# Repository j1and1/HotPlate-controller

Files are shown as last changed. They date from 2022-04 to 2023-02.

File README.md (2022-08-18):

# Hotplate reflow controller

This is still a work in progress, and controller code has issues of overshooting the target temperature **use at your own risk.** 

This is a implementation of temperature control of heated plate for reflow soldering.

## Wiring

To make this you will need:
1. Arduino pro mini (or any other microcontroller)
2. Thermal resistor (I used 100k one from my 3d printer spares)
3. 4.7kOhm resistor for temperature resistor pullup
4. 10uF capacitor for stabilizing sensor value
5. Nokia 5510 display module (Or other display module... code might need to be patched for this though)
6. Solid state relay (use solid state relay to avoid arking when Arduino enables disables the output pin)
7. if Arduino runs on 5V you will need additional 5 10k resistors and one 1kOhm resistors on the SPI line ment for display.

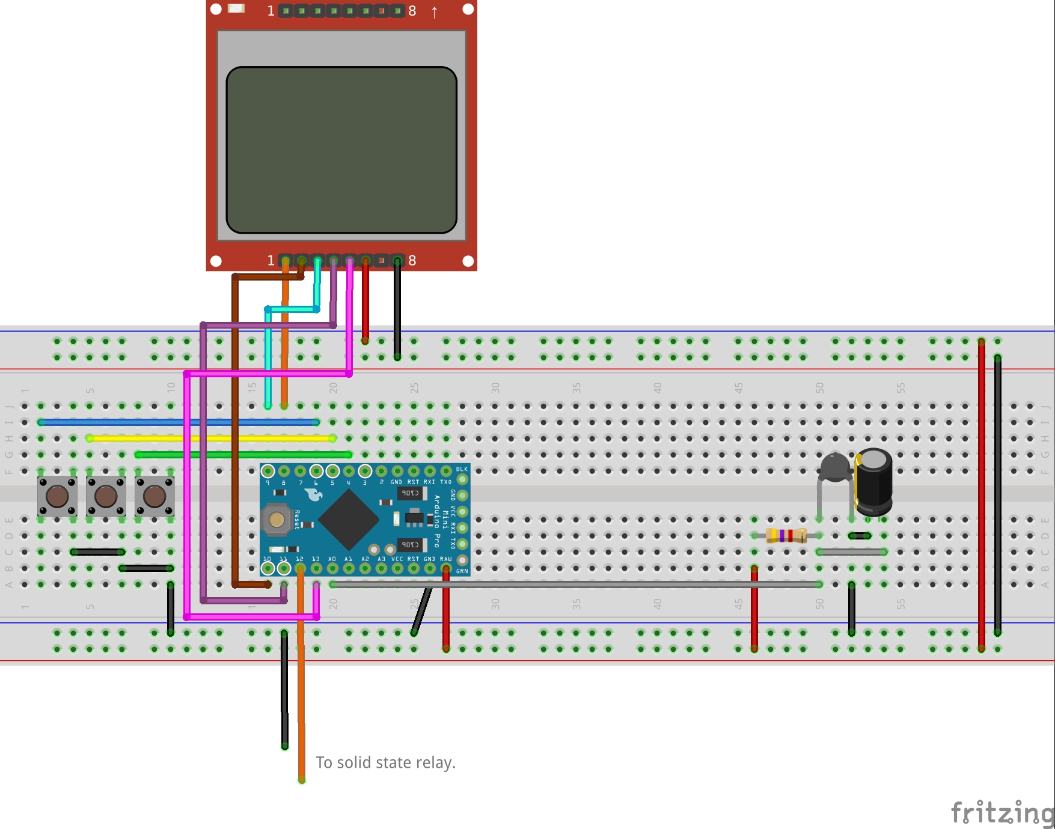
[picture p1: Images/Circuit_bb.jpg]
Schematic


## Compiling code

To compile Arduino code you will need few additional libraries.
1. Thermistor library [from here](https://github.com/miguel5612/ThermistorLibrary) or Arduino IDE library section
2. Adafruit PCD8544 library from Arduino IDE library section [or here](https://github.com/adafruit/Adafruit-PCD8544-Nokia-5110-LCD-library). Dont forget to install dependencies for it too.

## Known issues
- Thermal runaway algorithm is ignoring the state of solid state relay output pin
- Controller code does not account for thermal mass of the heater and plate. This will get solved once PID algorithm is added.

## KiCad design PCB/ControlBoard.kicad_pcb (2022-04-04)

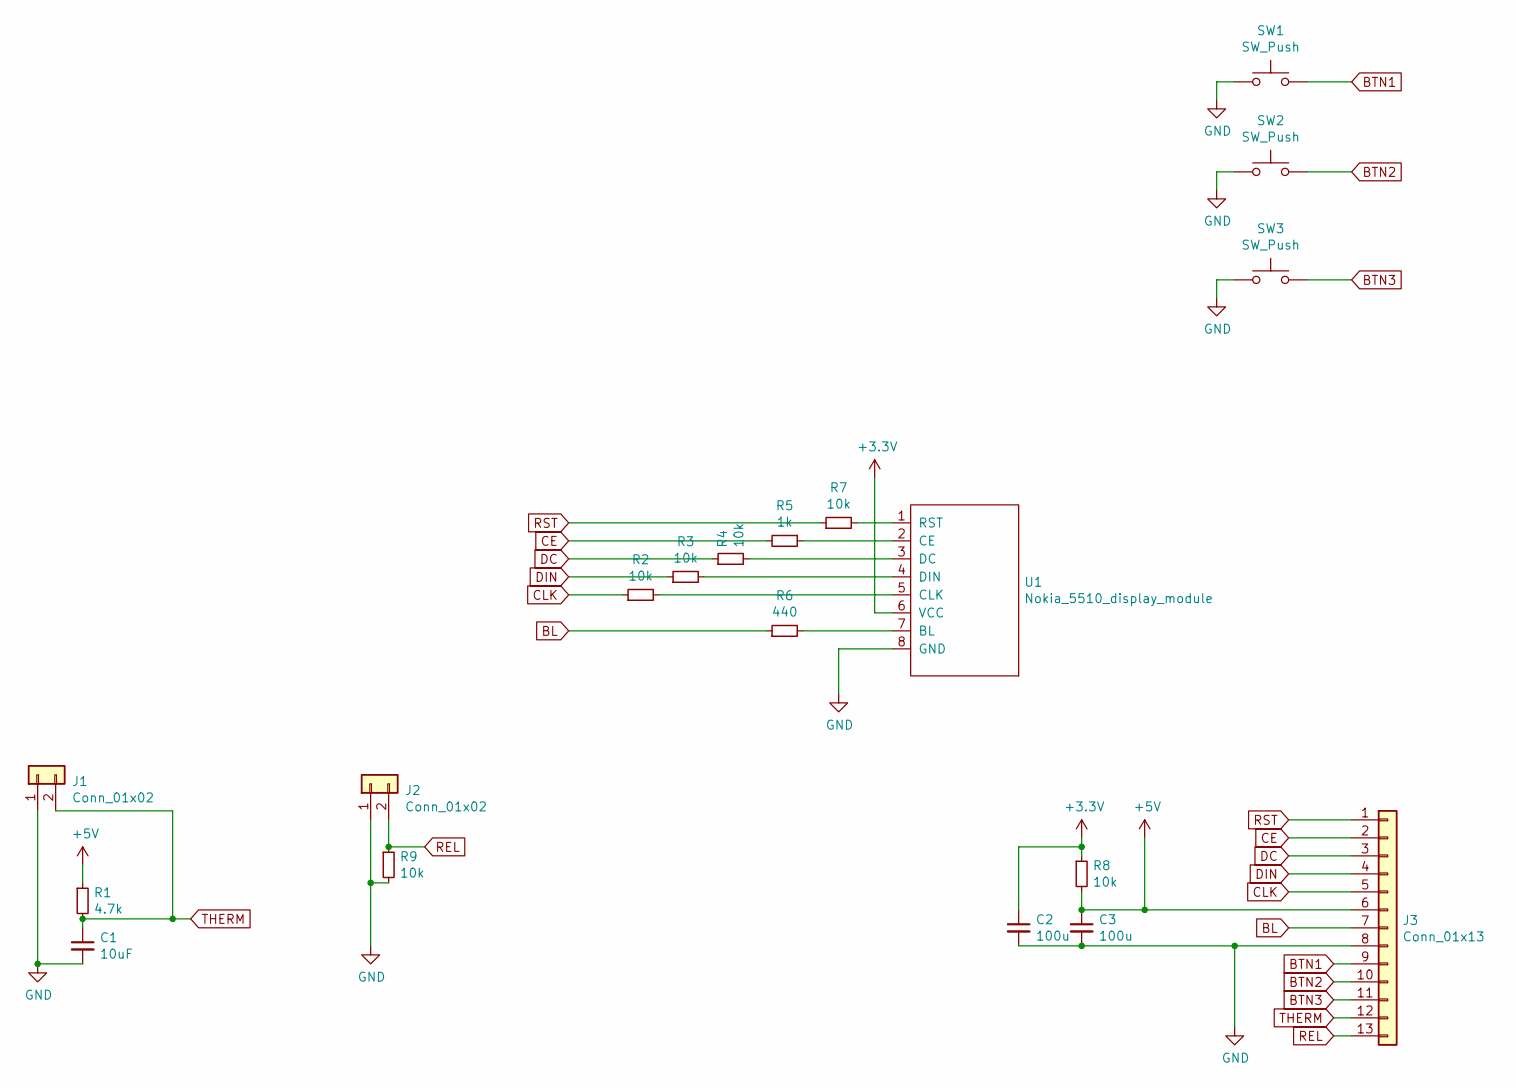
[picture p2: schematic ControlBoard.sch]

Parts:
C1: 10uF; C_0603_1608Metric_Pad1.08x0.95mm_HandSolder
C2, C3: 100u; C_0603_1608Metric_Pad1.08x0.95mm_HandSolder
J1, J2: Conn_01x02; PinHeader_1x02_P2.54mm_Horizontal
J3: Conn_01x13; PinHeader_1x13_P2.54mm_Vertical
R1: 4.7k; R_0402_1005Metric_Pad0.72x0.64mm_HandSolder
R2, R3, R4, R7, R8, R9: 10k; R_0402_1005Metric_Pad0.72x0.64mm_HandSolder
R5: 1k; R_0402_1005Metric_Pad0.72x0.64mm_HandSolder
R6: 440; R_0402_1005Metric_Pad0.72x0.64mm_HandSolder
SW1, SW2, SW3: SW_Push; SW_PUSH_6mm
U1: Nokia_5510_display_module; NOKIA_5510_display_module

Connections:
+3V3: C2.1, R8.1, U1.6 (VCC)
+5V: C3.1, J3.6, R1.1, R8.2
BL: J3.7, R6.1
BTN1: J3.9, SW1.2
BTN2: J3.10, SW2.2
BTN3: J3.11, SW3.2
CE: J3.2, R5.2
CLK: J3.5, R2.1
DC: J3.3, R4.1
DIN: J3.4, R3.1
GND: C1.2, C2.2, C3.2, J1.1, J2.1, J3.8, R9.2, SW1.1, SW2.1, SW3.1, U1.8 (GND)
unnamed: R2.2, U1.5 (CLK)
unnamed: R3.2, U1.4 (DIN)
unnamed: R4.2, U1.3 (DC)
unnamed: R5.1, U1.2 (CE)
unnamed: R6.2, U1.7 (BL)
unnamed: R7.2, U1.1 (RST)
REL: J2.2, J3.13, R9.1
RST: J3.1, R7.1
THERM: C1.1, J1.2, J3.12, R1.2

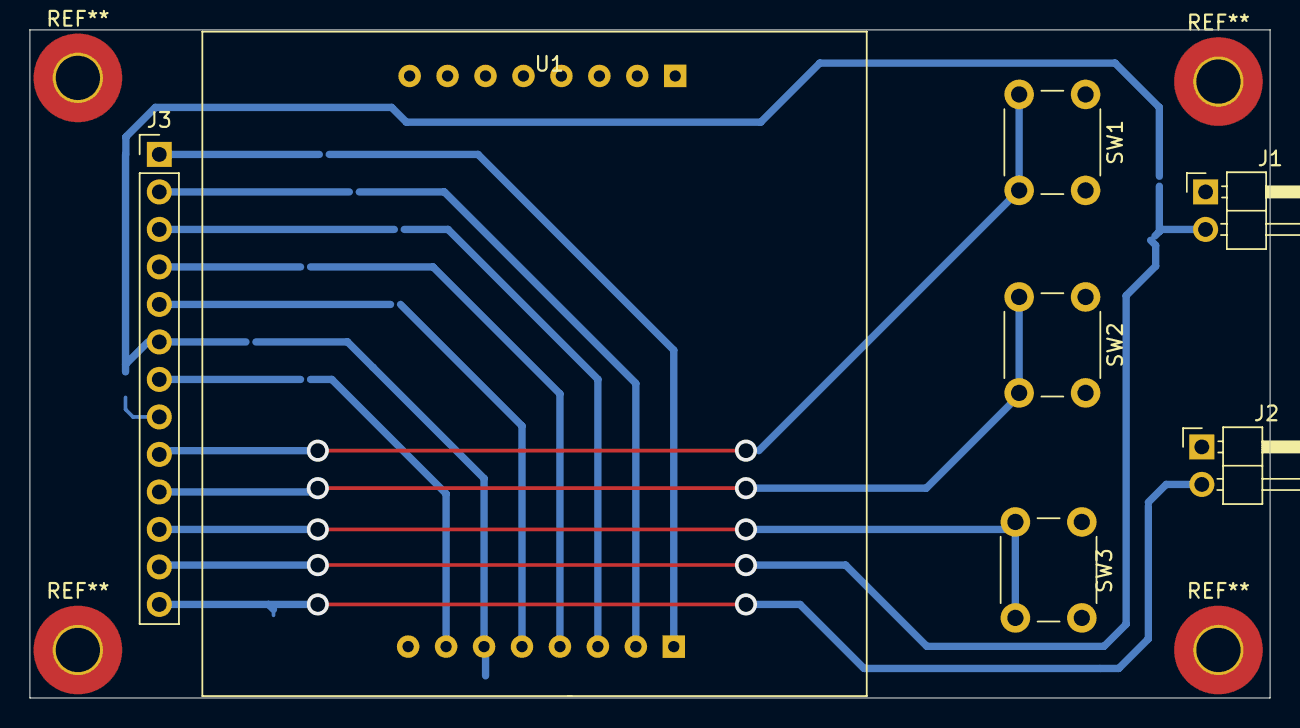
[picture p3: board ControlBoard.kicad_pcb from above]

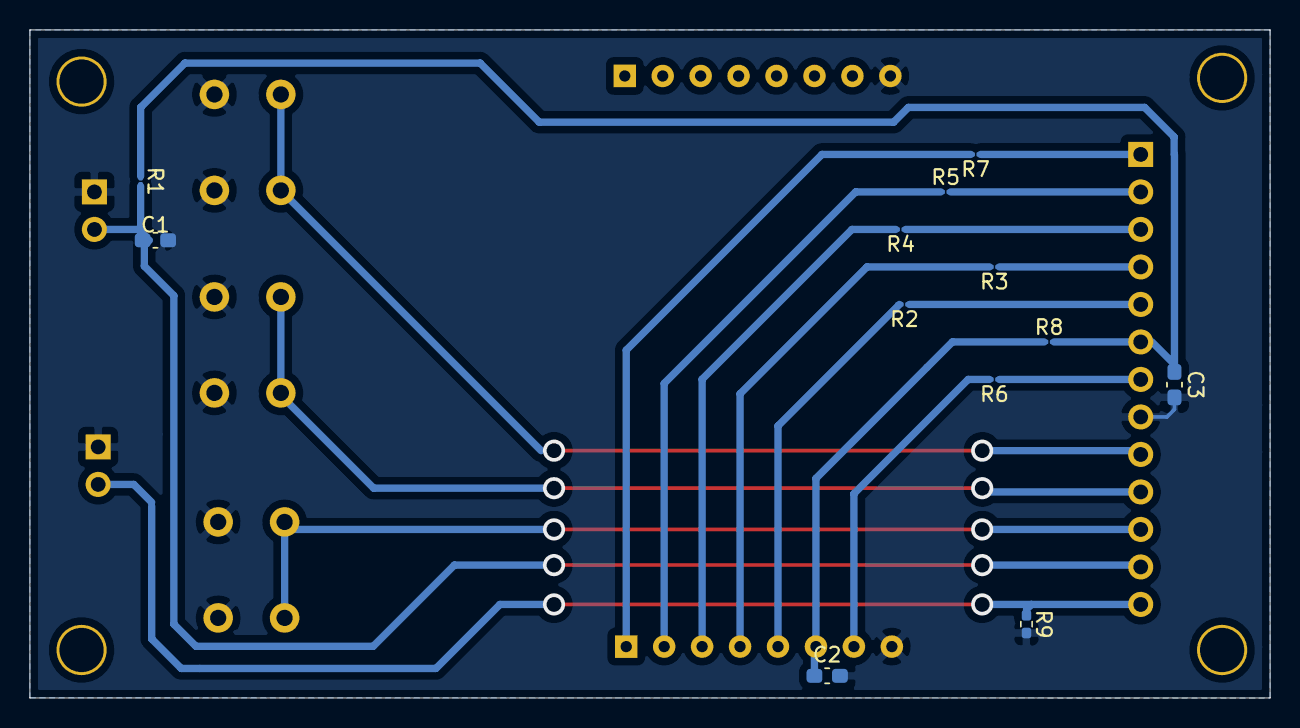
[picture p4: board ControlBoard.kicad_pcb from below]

Board: 2 copper layers, 84.0 x 45.2 mm, 19 parts (12 on the bottom side), 20 nets.

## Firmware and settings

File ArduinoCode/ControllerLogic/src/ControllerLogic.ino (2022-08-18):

// Display includes -> Adafruit PCD8544 lib
#include <Adafruit_GFX.h>
#include <Adafruit_PCD8544.h>

#include "Configuration.h"
#include "TemperatureControl.h"

TemperatureControl tc;

// Display related variables
// Software SPI (slower updates, more flexible pin options):
// pin 13 - Serial clock out (SCLK)
// pin 11 - Serial data out (DIN)
// pin 9 - Data/Command select (D/C)
// pin 10 - LCD chip select (CS)
// pin 8 - LCD reset (RST)
Adafruit_PCD8544 display = Adafruit_PCD8544(13, 11, 9, 10, 8);

// menu related variables
int menuitem = 0;
int page = 0;

volatile boolean up = false;
volatile boolean down = false;
volatile boolean middle = false;

int downButtonState = 0;
int upButtonState = 0;  
int selectButtonState = 0;          
int lastDownButtonState = 0;
int lastSelectButtonState = 0;
int lastUpButtonState = 0;
// menu related stuff end

void setup() {
  // put your setup code here, to run once:
  pinMode(BTN1, INPUT_PULLUP);
  pinMode(BTN2, INPUT_PULLUP);
  pinMode(BTN3, INPUT_PULLUP);

  pinMode(OUT1, OUTPUT);
  digitalWrite(OUT1, LOW);

  Serial.begin(9600);

  // start display related activities
  display.begin();
  display.setContrast(50);
  display.display(); // show splashscreen
  delay(2000);
  display.clearDisplay(); // clears the screen and buffer
  display.setRotation(2);
}

void loop() {
  displayMenu();
  // check if thermal runaway
  if (tc.isThermalRunawayDetected())
  {
    page = 2;
  }
  else
  {
    doMenuAction();
  }
  tc.runLoop();
}

void displayMenu()
{
  if (page == 0) 
  {    
    display.setTextSize(1);
    display.clearDisplay();
    display.setTextColor(BLACK, WHITE);
    display.setCursor(15, 0);
    display.print("MAIN MENU");
    display.drawFastHLine(0,10,83,BLACK);
    display.setCursor(0, 15);
   
    if (menuitem==0) 
    { 
      display.setTextColor(WHITE, BLACK);
    }
    else 
    {
      display.setTextColor(BLACK, WHITE);
    }
    display.print(">Fixed Temp");
    display.setCursor(0, 25);

    if (menuitem==1) 
    { 
      display.setTextColor(WHITE, BLACK);
    }
    else 
    {
      display.setTextColor(BLACK, WHITE);
    }
    display.print(">Reflow curve");

    display.setTextColor(BLACK, WHITE);
    display.setCursor(0, 35);
    display.print("Temp C: ");
    display.print(tc.getLastTemp());
    display.display();
  }
  else if (page == 1) 
  {
    display.setTextSize(1);
    display.clearDisplay();
    display.setTextColor(BLACK, WHITE);
    display.setCursor(15, 0);
    display.print("Target temp:");
    display.drawFastHLine(0,10,83,BLACK);
    display.setCursor(5, 15);
    display.print("Value");
    display.setTextSize(2);
    display.setCursor(5, 25);
    display.print((int) tc.getTargetTemp());
 
    display.setTextSize(2);
    display.display();
  }
  else if (page == 2) // thermal runaway
  {
    display.setTextSize(1);
    display.clearDisplay();
    display.setTextColor(BLACK, WHITE);
    display.setCursor(15, 0);
    display.print("Error");
    display.drawFastHLine(0,10,83,BLACK);
    display.setCursor(5, 15);
    display.print("Thermal");
    display.setCursor(5, 25);
    display.print("runaway");
    display.display();
  }
  else
  {
    display.setTextSize(1);
    display.clearDisplay();
    display.setTextColor(BLACK, WHITE);
    display.setCursor(15, 0);
    display.print("Heating");
    display.drawFastHLine(0,10,83,BLACK);
    display.setCursor(5, 15);
    display.print("Time:");
    const unsigned long t = (millis() - tc.getHeaterStartTime()) / 1000;
    display.print(t);
    display.setCursor(5, 25);
    display.print("T:");
    display.print(tc.getLastTemp());
    display.print("/");
    display.print((int) tc.getTargetTemp());
    display.display();
  }
}

void doMenuAction()
{
  downButtonState = digitalRead(BTN3);
  selectButtonState = digitalRead(BTN2);
  upButtonState =   digitalRead(BTN1);

  checkIfDownButtonIsPressed();
  checkIfUpButtonIsPressed();
  checkIfSelectButtonIsPressed();

  if (up && page == 0 ) {
    up = false;
    menuitem--;
    if (menuitem== -1)
    {
      menuitem = 1;
    }      
  }
  else if (up && page == 1 ) 
  {
    tc.setTargetTemp(tc.getTargetTemp() + 1);
  }


  if (down && page == 0) {
    down = false;
    menuitem++;
    if (menuitem == 2) 
    {
      menuitem=0;
    }      
  }
  else if (down && page == 1) 
  {
    tc.setTargetTemp(tc.getTargetTemp() - 1);
  }

  if (middle) {
    middle = false;

    // set fixed temperature
    if (page == 0 && menuitem==0) {
      page = 1;
    }
    // reflow curve
    else if (page == 0 && menuitem == 1)
    {
      tc.setUseReflowCurve(true);
      tc.setIsHeating(true);
      page = 3;
    }
    // heat the 
    else if (page == 1) {
      tc.setUseReflowCurve(false);
      tc.setIsHeating(true);
      page = 3;
    }
    // disable heating and move back
    else
    {
      tc.setIsHeating(false);
      page = 0;
    }
  }
}

void checkIfDownButtonIsPressed()
{
  if (downButtonState != lastDownButtonState) 
  {
    if (downButtonState == 0) 
    {
      down = true;
    }
    else
    {
      down = false;
    }
    delay(50);
  }
  lastDownButtonState = downButtonState;
}

void checkIfUpButtonIsPressed()
{
  if (upButtonState != lastUpButtonState) 
  {
    if (upButtonState == 0) {
      up = true;
    }
    else
    {
      up = false;
    }
    delay(50);
  }
  lastUpButtonState = upButtonState;
}

void checkIfSelectButtonIsPressed()
{
  if (selectButtonState != lastSelectButtonState) 
  {
    if (selectButtonState == 0) {
      middle = true;
    }
    delay(50);
  }
  lastSelectButtonState = selectButtonState;
}

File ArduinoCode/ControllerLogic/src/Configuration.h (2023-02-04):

#pragma once

#include <Arduino.h>

// pin definitions
#define BTN1 4 // up
#define BTN2 5 // select
#define BTN3 6 // down
#define SENS1 A0 // thermal resistor pin
#define OUT1 12 // Solid state relay pin

#define SENS1_TYPE 1 // thermistor type

// thermal runaway timeout - the time after the heater disables if there are no temperature updates
#define THERMAL_RUNAWAY_TIMEOUT 60000 // milliseconds
#define THERMAL_RUNAWAY_DEGREE_DIFF 3
// temperature PID controller values (just stole these from my 3D printer configuration)
#define P 13.12
#define I 1.522
#define D 65.83
// maximum temperature the heatplate can reach (according to spec sheet)
#define MAX_TEMP 260

// reflow curve I found on the interwebs
const byte CURVE_SIZE = 6;
const double CURVE_TIME[] = { 0.0, 90.0, 180.0, 240.0, 270.0, 360.0};
const double CURVE_TEMP[] = { 0.0, 150.0, 150.0, 240.0, 240.0, 0};

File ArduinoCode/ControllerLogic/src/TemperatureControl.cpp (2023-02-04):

#include "TemperatureControl.h"

TemperatureControl::TemperatureControl()
  : therm1(SENS1, SENS1_TYPE)
{
  // setup output pin and set it to low state
  pinMode(OUT1, OUTPUT);
  digitalWrite(OUT1, LOW);
}

void TemperatureControl::runLoop()
{
  if ((targetTemp > 0.0 || useCurve) && isHeating)
  {
    double currentTemp = therm1.analog2temp();
    // detect thermal runaway
    if (millis() - lastTempIncrease >= THERMAL_RUNAWAY_TIMEOUT)
    {
      isHeating = false;
      thermalRunawayDetected = true;
    }

    // find target temperature from curve
    // update target temperature from reflow curve 
    if (useCurve)
    {
      // find time and target temp
      double currentRuntime = (double) ((millis() - heatingStart) / 1000);
      // check to see if we have more points in curve, if not then disable heating
      if (curvePhase + 1 >= CURVE_SIZE)
      {
        targetTemp = 0.0;
        isHeating = false;
        digitalWrite(OUT1, LOW);
        return;
      }
      
      if (currentRuntime >= CURVE_TIME[curvePhase + 1])
      {
        curvePhase++;
      }

      const double t1 = CURVE_TIME[curvePhase];
      const double t2 = CURVE_TIME[curvePhase + 1];
      const double p1 = CURVE_TEMP[curvePhase];
      const double p2 = CURVE_TEMP[curvePhase + 1];
      if (p1 == p2)
      {
        targetTemp = p2;
      }
      else
      {
        // find target temperature with linear interpulation
        targetTemp = ((p2 - p1) / (t2 - t1)) * (((double) currentRuntime) - t1);
      }
    }

    // TODO: add PID controller here (because of thermal mass of the heater), and adjust thermal runaway code to take into account state of the output pin
    const auto now = millis();
    const auto dt = static_cast<double>(now - lastPidTime) / 1000.0;
    const double diff = targetTemp - currentTemp;
    integral = integral + diff * static_cast<double>(dt);
    const double dxdt = (diff - lastDiff) / static_cast<double>(dt);
    lastDiff = diff;
    lastPidTime = now;

    const double output = diff * P + integral * I + dxdt * D;
    if (output > 0.0)
    {
      digitalWrite(OUT1, HIGH);
    }
    else
    {
      digitalWrite(OUT1, LOW);
    }
    Serial.println(output);

    // update time variable used for thermal runaway if the temperature is within spec
    const double highBound = lastTemp + THERMAL_RUNAWAY_DEGREE_DIFF;
    const double lowBound = lastTemp - THERMAL_RUNAWAY_DEGREE_DIFF;
    if (lowBound <= currentTemp && currentTemp <= highBound)
    {
      lastTempIncrease = millis();
    }      
    lastTemp = currentTemp;
  }
  else
  {
    lastTemp = therm1.analog2temp();
    digitalWrite(OUT1, LOW);
  }
}

void TemperatureControl::setIsHeating(bool newValue) 
{ 
  isHeating = newValue; 
  if (newValue)
  {
    curvePhase = 0;
    lastPidTime = heatingStart = lastTempIncrease = millis();
    lastDiff = 0.0;
    integral = 0.0;
  }
}

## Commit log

2022-03-31 Created rough placement of control board... need to recheck footprint sizes
    [ControlBoard.kicad_pcb, ControlBoard.sch]
2022-04-01 Board done
    [ControlBoard.kicad_pcb, ControlBoard.sch]
2022-04-04 Fixed some holes and footprints so I can mill this at home
    [ControlBoard.kicad_pcb]
2022-08-18 Add README.md and implement controller code
    * Initial commit of control code
    * Moved the thermal control-related code to separate files
    * Controller board now controls stuff
    * fix thermal runaway
    * Added readme
    [Configuration.h]
2023-02-04 Added PID for temperature control and moved to Platformio
    [Configuration.h]
